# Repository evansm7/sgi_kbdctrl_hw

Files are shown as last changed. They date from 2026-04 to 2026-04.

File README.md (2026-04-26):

# SGI Indigo PS/2 keyboard/mouse adapter PCB

26 April 2026

This is the PCB companion to the [sgi_indigo_kbdctrl firmware](https://github.com/evansm7/sgi_indigo_kbdctrl) project. 

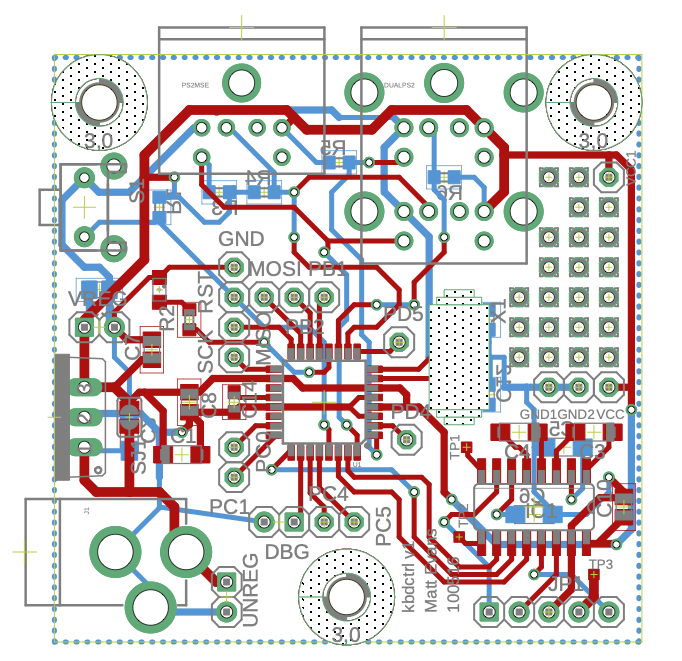
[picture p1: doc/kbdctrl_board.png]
Render of PCB layout


Has enough on board to be self-powered using the 8V from the Indigo, or can be built with a barrel jack to take 5VDC (which is probably nicer for the SGI).

Can be built with a dual/stacked PS/2 connector for keyboard/mouse in one footprint, or two one-socket connectors side by side.

# License

sgi_kbdctrl_hw is copyright 2016 Matt Evans.

This work is licensed under the Creative Commons Attribution-NonCommercial-ShareAlike 3.0 Unported License. To view a copy of this license, visit http://creativecommons.org/licenses/by-nc-sa/3.0/ or send a letter to Creative Commons, PO Box 1866, Mountain View, CA 94042, USA.

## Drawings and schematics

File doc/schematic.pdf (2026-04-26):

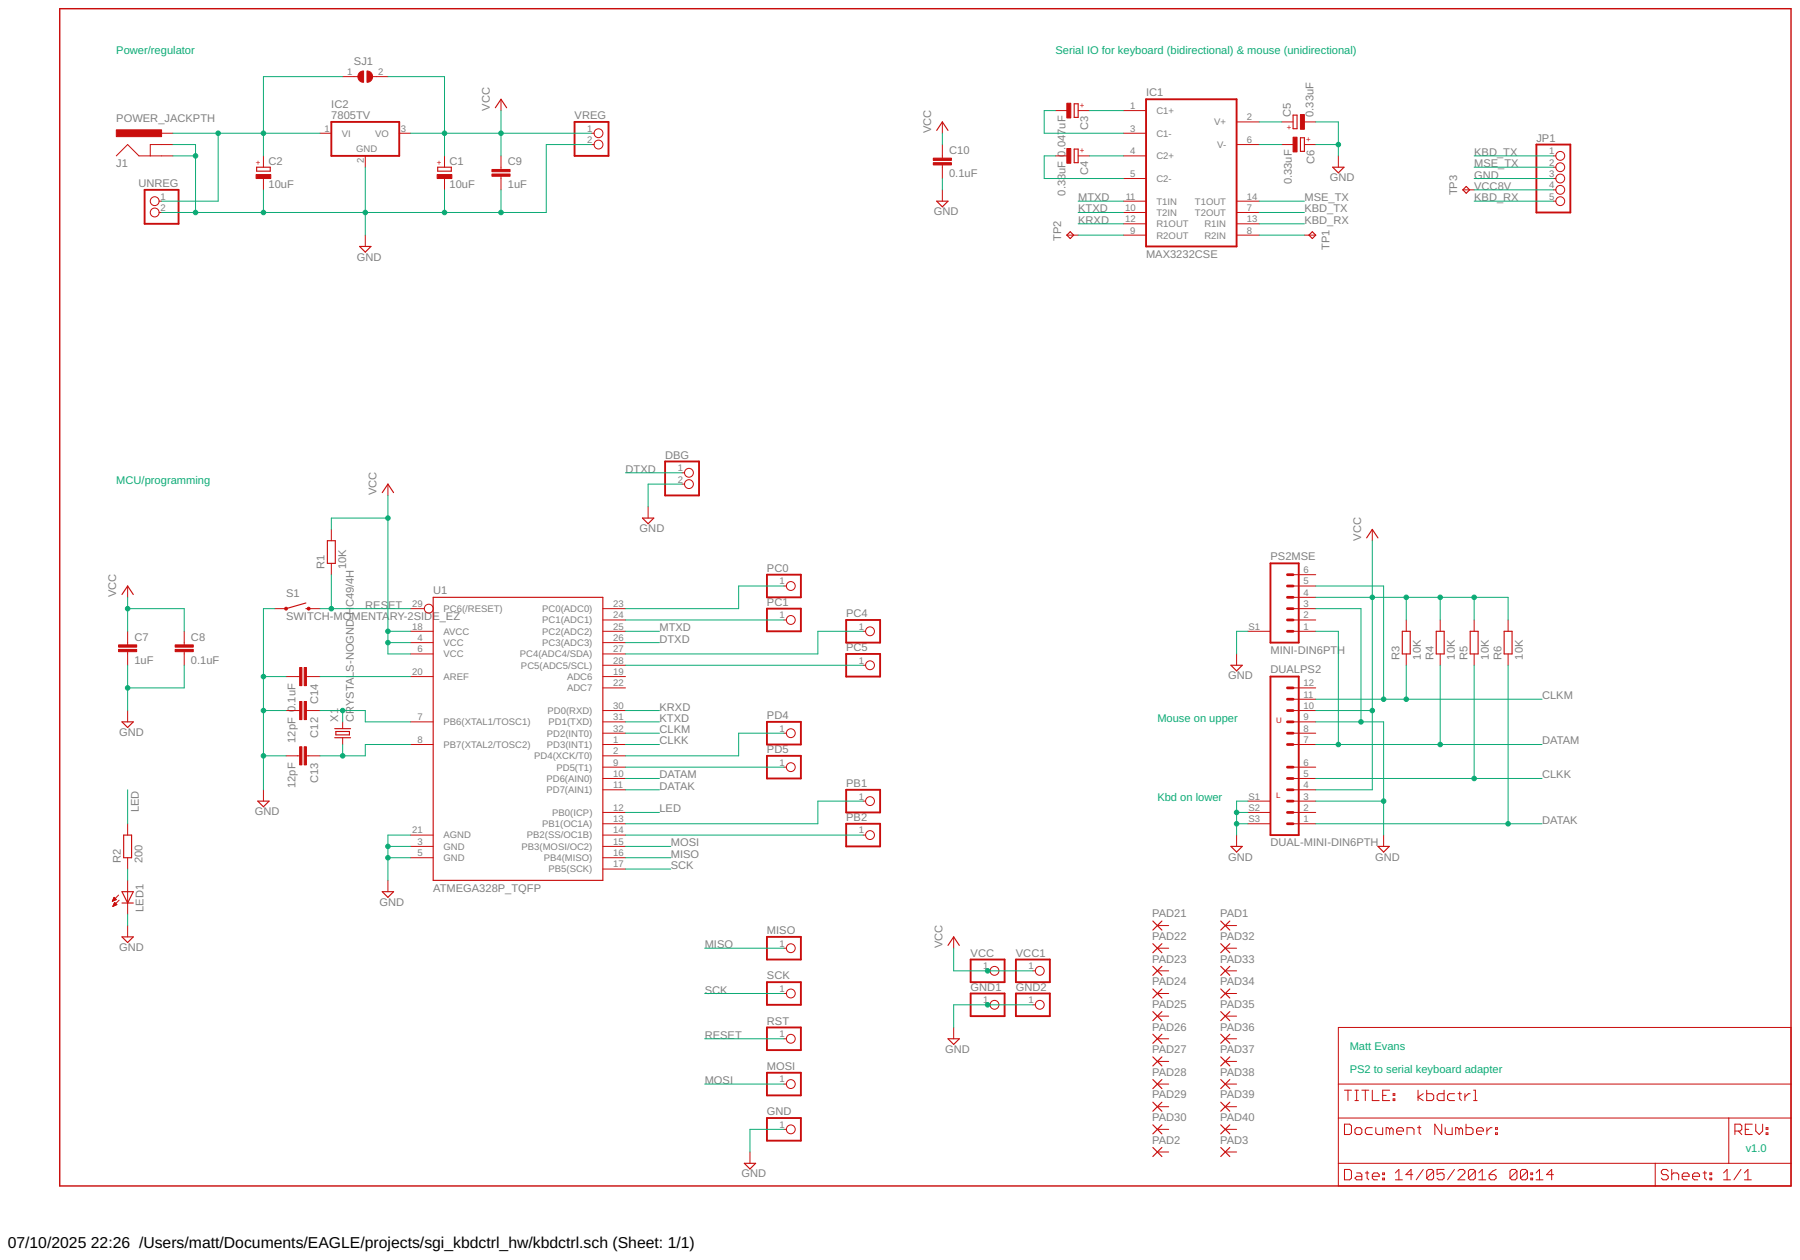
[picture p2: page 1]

10

Matt Evans PS2 to serial keyboard adapter

07/10/2025 22:26 /Users/matt/Documents/EAGLE/projects/sgi_kbdctrl_hw/kbdctrl.sch (Sheet: 1/1)

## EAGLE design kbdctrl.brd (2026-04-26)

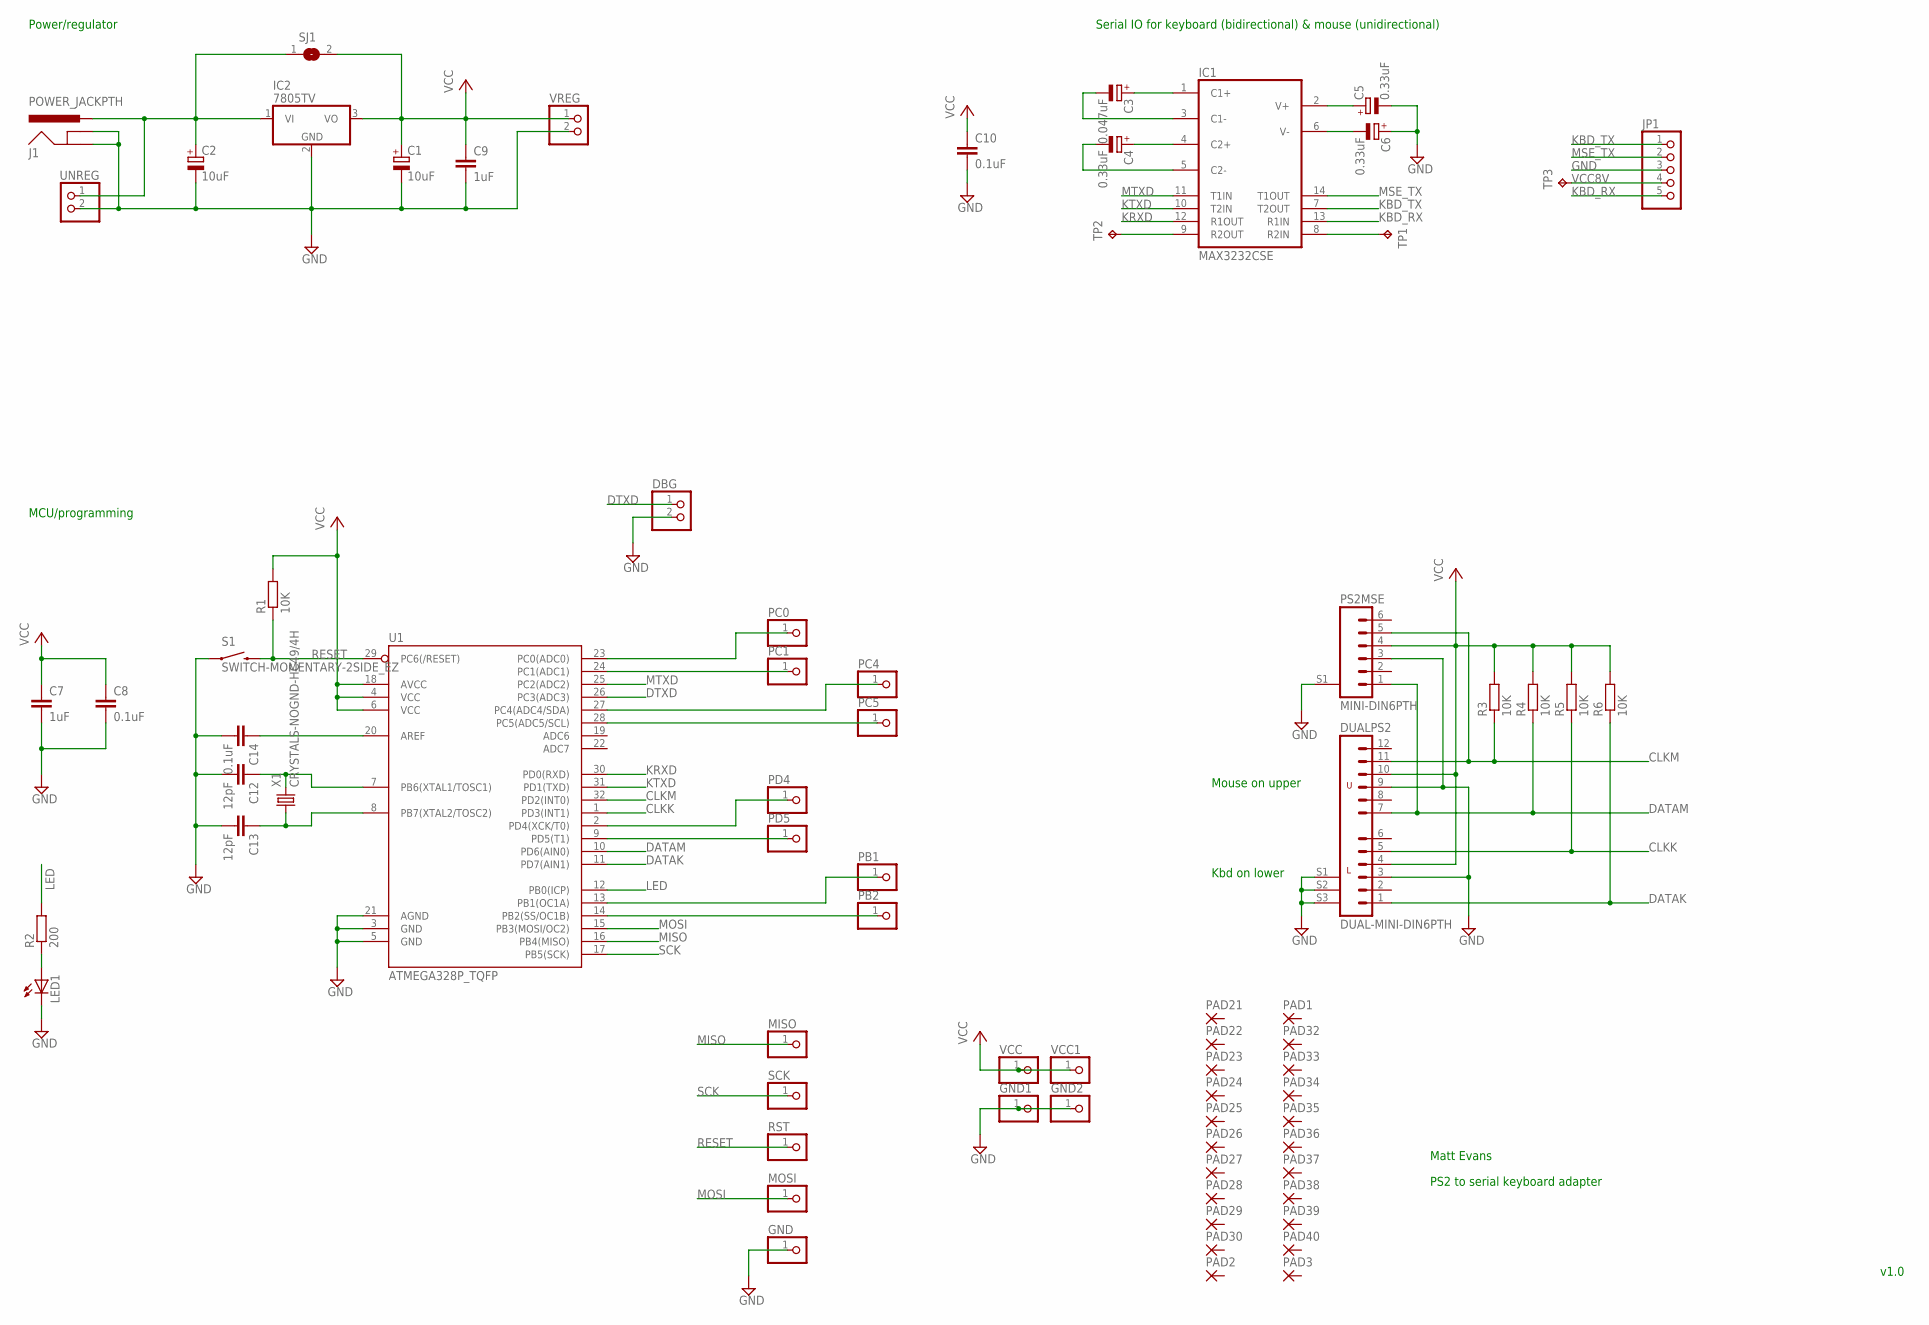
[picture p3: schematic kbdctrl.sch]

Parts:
C1, C2: 10uF; SMC_P
C3: 0.047uF; SMC_P
C4, C5, C6: 0.33uF; SMC_P
C7, C9: 1uF; C0805
C8, C10: 0.1uF; C0805
C12, C13: 12pF; C0603
C14: 0.1uF; C0603
DBG: PINHD-1X2; 1X02
DUALPS2: DUAL-MINI-DIN6PTH; DUAL-MINI-DIN6
GND, GND1, GND2: PINHD-1X1; 1X01
IC1: MAX3232CSE; SO16
IC2: 7805TV; TO220V
J1: POWER_JACKPTH; POWER_JACK_PTH
JP1: PINHD-1X5; 1X05
LED1: LEDSML0805; SML0805
MISO: PINHD-1X1; 1X01
MOSI: PINHD-1X1; 1X01
PAD1, PAD2, PAD3, PAD21, PAD22, PAD23, PAD24, PAD25, PAD26, PAD27, PAD28, PAD29, PAD30, PAD32, PAD33, PAD34, PAD35, PAD36, PAD37, PAD38, PAD39, PAD40: 1,6/0,9
PB1, PB2: PINHD-1X1; 1X01
PC0, PC1, PC4, PC5: PINHD-1X1; 1X01
PD4, PD5: PINHD-1X1; 1X01
PS2MSE: MINI-DIN6PTH; MINI-DIN6
R1, R3, R4, R5, R6: 10K; R0603
R2: 200; R0603
RST: PINHD-1X1; 1X01
S1: SWITCH-MOMENTARY-2SIDE_EZ; TACTILE-PTH-SIDEEZ
SCK: PINHD-1X1; 1X01
SJ1: SJ
TP1, TP2, TP3: TPTP09SQ; TP09SQ
U1: ATMEGA328P_TQFP; TQFP32-08
UNREG: PINHD-1X2; 1X02
VCC, VCC1: PINHD-1X1; 1X01
VREG: PINHD-1X2; 1X02
X1: CRYSTALS-NOGND-HC49/4H; HC49

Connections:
CLKK: DUALPS2.5, R5.1, U1.1 (PD3(INT1))
CLKM: DUALPS2.11, PS2MSE.5, R3.1, U1.32 (PD2(INT0))
DATAK: DUALPS2.1, R6.1, U1.11 (PD7(AIN1))
DATAM: DUALPS2.7, PS2MSE.1, R4.1, U1.10 (PD6(AIN0))
DTXD: DBG.1, U1.26 (PC3(ADC3))
GND: C1.-, C2.-, C5.-, C6.+, C7.2, C8.2, C9.2, C10.2, C12.2, C13.2, C14.2, DBG.2, DUALPS2.3, DUALPS2.9, DUALPS2.S1, DUALPS2.S2, DUALPS2.S3, GND.1, GND1.1, GND2.1, IC1.15 (GND), IC2.2 (GND), J1.GND, J1.GNDBREAK, JP1.3, LED1.C, PS2MSE.3, PS2MSE.S1, S1.1, U1.3 (GND), U1.5 (GND), U1.21 (AGND), UNREG.2, VREG.2
KBD_RX: IC1.13 (R1IN), JP1.5
KBD_TX: IC1.7 (T2OUT), JP1.1
KRXD: IC1.12 (R1OUT), U1.30 (PD0(RXD))
KTXD: IC1.10 (T2IN), U1.31 (PD1(TXD))
LED: R2.2, U1.12 (PB0(ICP))
MISO: MISO.1, U1.16 (PB4(MISO))
MOSI: MOSI.1, U1.15 (PB3(MOSI/OC2))
MSE_TX: IC1.14 (T1OUT), JP1.2
MTXD: IC1.11 (T1IN), U1.25 (PC2(ADC2))
unnamed: C3.-, IC1.3 (C1-)
unnamed: C4.+, IC1.4 (C2+)
unnamed: C12.1, U1.7 (PB6(XTAL1/TOSC1)), X1.2
unnamed: C13.1, U1.8 (PB7(XTAL2/TOSC2)), X1.1
unnamed: C4.-, IC1.5 (C2-)
unnamed: C2.+, IC2.1 (VI), J1.PWR, SJ1.1, UNREG.1
unnamed: C14.1, U1.20 (AREF)
unnamed: C3.+, IC1.1 (C1+)
unnamed: C5.+, IC1.2 (V+)
unnamed: C6.-, IC1.6 (V-)
unnamed: IC1.9 (R2OUT), TP2.TP
unnamed: IC1.8 (R2IN), TP1.TP
unnamed: LED1.A, R2.1
unnamed: PB1.1, U1.13 (PB1(OC1A))
unnamed: PD5.1, U1.9 (PD5(T1))
unnamed: PD4.1, U1.2 (PD4(XCK/T0))
unnamed: PC5.1, U1.28 (PC5(ADC5/SCL))
unnamed: PC1.1, U1.24 (PC1(ADC1))
unnamed: PC0.1, U1.23 (PC0(ADC0))
PB2: PB2.1, U1.14 (PB2(SS/OC1B))
PC4: PC4.1, U1.27 (PC4(ADC4/SDA))
RESET: R1.1, RST.1, S1.2, U1.29 (PC6(/RESET))
SCK: SCK.1, U1.17 (PB5(SCK))
VCC: C1.+, C7.1, C8.1, C9.1, C10.1, DUALPS2.4, DUALPS2.10, IC1.16 (VCC), IC2.3 (VO), PS2MSE.4, R1.2, R3.2, R4.2, R5.2, R6.2, SJ1.2, U1.4 (VCC), U1.6 (VCC), U1.18 (AVCC), VCC.1, VCC1.1, VREG.1
VCC8V: JP1.4, TP3.TP

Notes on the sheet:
Matt Evans
PS2 to serial keyboard adapter
Kbd on lower
Mouse on upper
Serial IO for keyboard (bidirectional) & mouse (unidirectional)
Power/regulator
MCU/programming
v1.0

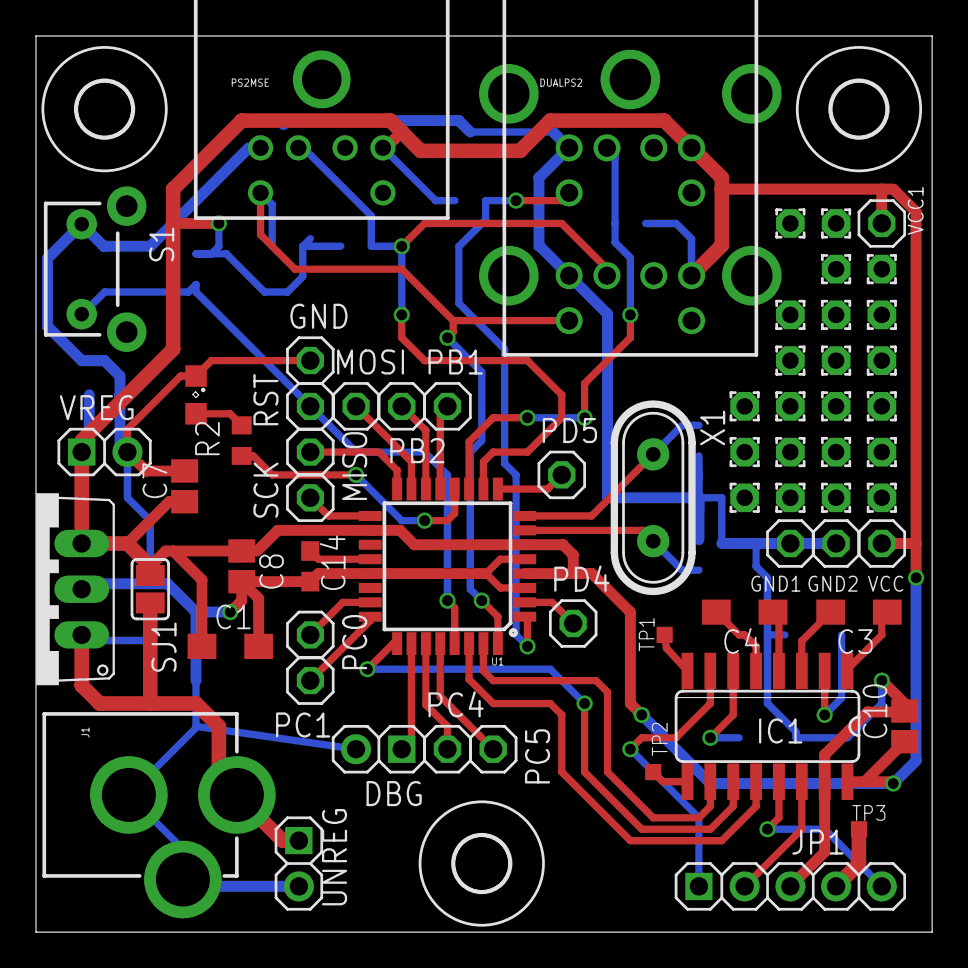
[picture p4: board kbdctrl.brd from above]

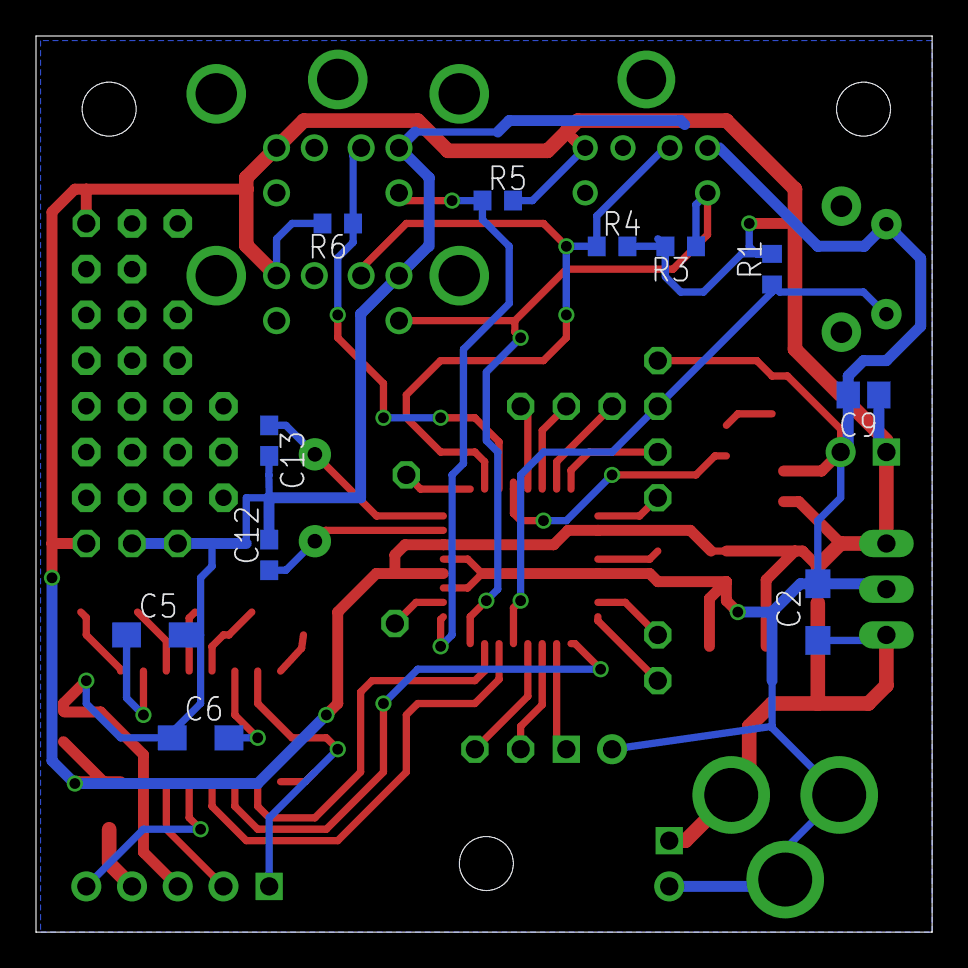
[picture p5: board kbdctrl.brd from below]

Board: 2 copper layers, 49.8 x 49.8 mm, 78 parts (11 on the bottom side), 40 nets.

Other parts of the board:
U$2, U$3, U$4: 3,0

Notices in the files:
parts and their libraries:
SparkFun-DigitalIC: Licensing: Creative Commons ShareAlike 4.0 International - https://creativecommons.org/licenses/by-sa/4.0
